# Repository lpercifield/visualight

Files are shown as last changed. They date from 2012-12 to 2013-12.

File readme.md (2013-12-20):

###**Visualight Hardware and Firmware**
Server code is available from this repo

####**Release Candidate GREEN**

Current Firmware Version: 1.1 (RC GREEN) library
More information: [Visualight.org][1]

* Arduino Library can be found in Firmware > Visualight
* Wiki can be found [here][2]

------
	
####Features:
* Show color (version) of firmware when you do a reset
* Ability to enable/disable WiFly LEDs from Arduino (top-level)
* Special character support in SSIDs (now supports &^%$#()!@ in network name)

####Fixes:
* Easier to reset WiFi with button (processButton() added to reconnect loops
* Debug toggling from Arduino?

[1]:http://visualight.org
[2]:https://github.com/lpercifield/visualight/wiki
[3]:https://github.com/lpercifield/Visualight_Server

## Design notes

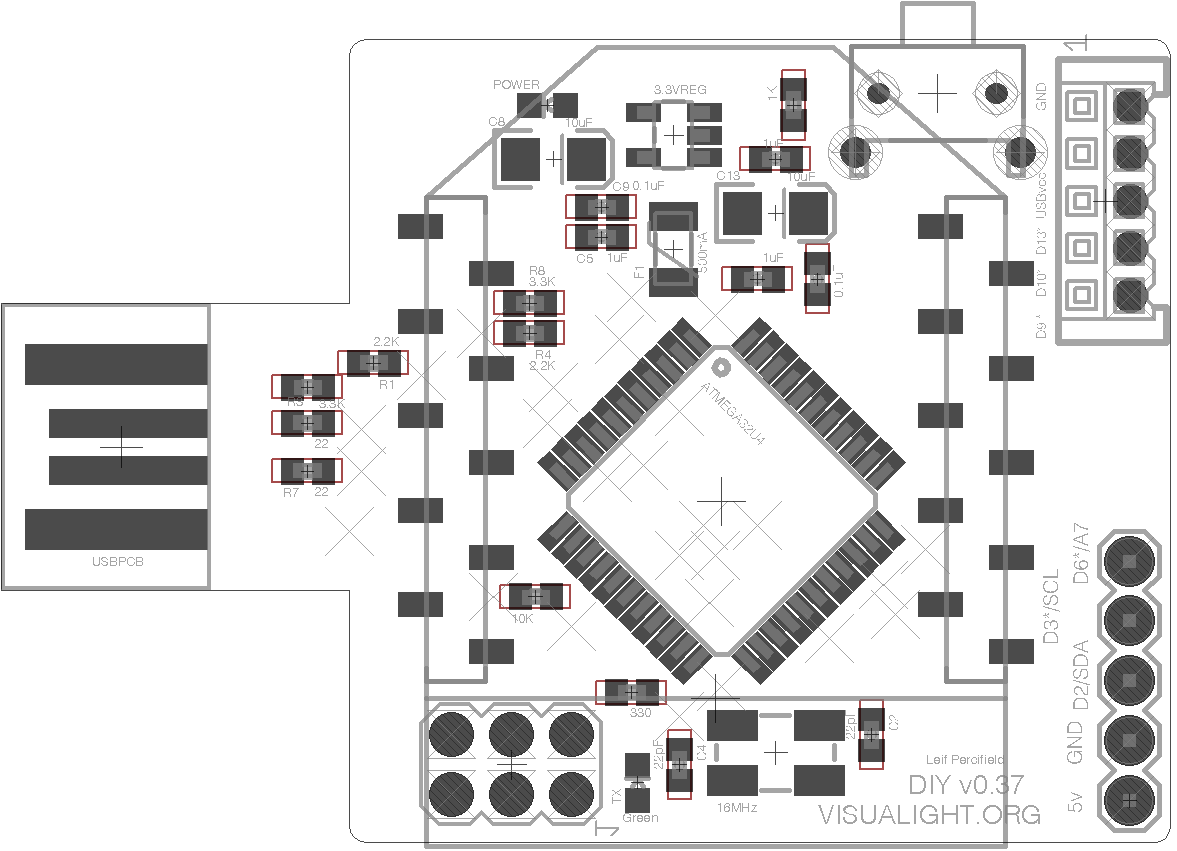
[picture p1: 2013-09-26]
Hardware/dev/DIY/DIY_037.png

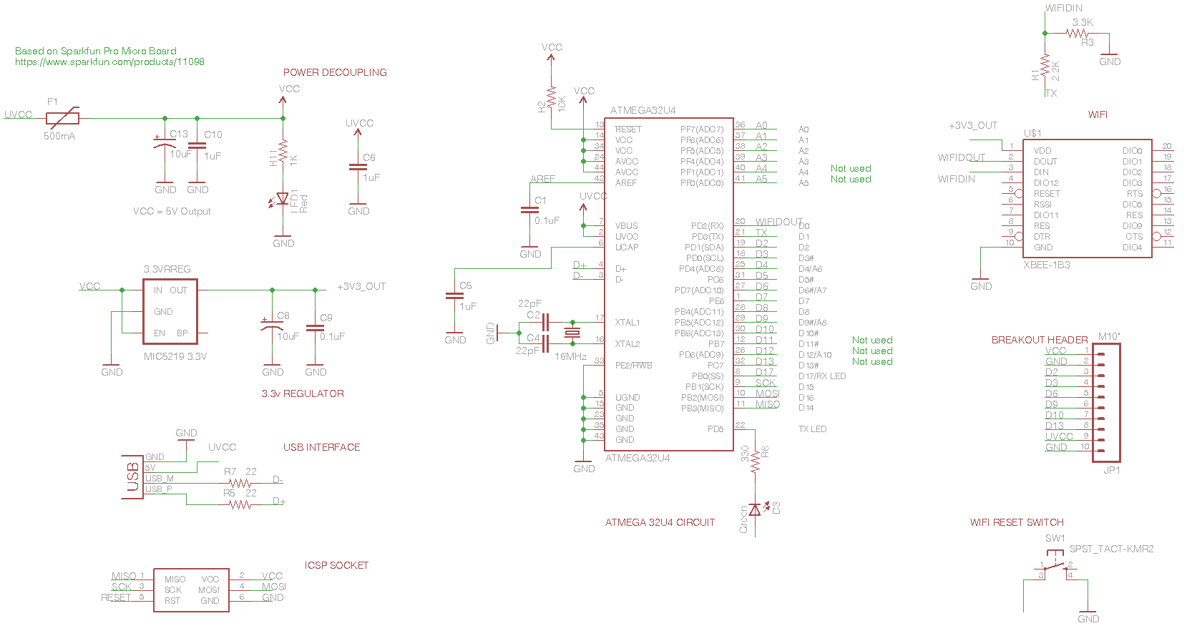
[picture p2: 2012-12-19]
Hardware/dev/DIY/DIY Schematic.png

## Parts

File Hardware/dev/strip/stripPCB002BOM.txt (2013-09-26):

Partlist exported from /Users/leifpercifield/Dropbox/visualightGithub/visualight/Hardware/strip/stripPCB002.sch at 8/27/13 11:21 AM

Qty Value                 Device                Package                   Parts       Description                                                                      MF MPN OC_FARNELL OC_NEWARK PROD_ID    VALUE       
1                         W237-4                W237-4                    X1          WAGO SCREW CLAMP                                                                        unknown    unknown                          
2   0.1uF                 CAP0402-CAP           0402-CAP                  C1, C9      Capacitor                                                                                                                           
1   10K                   RESISTOR0402-RES      0402-RES                  R2          Resistor                                                                                                                            
2   10uF                  CAP_POL1206           EIA3216                   C8, C13     Capacitor Polarized                                                                                                                 
1   16MHz                 CRYSTAL5X3            CRYSTAL-SMD-5X3           Y1          Crystals                                                                                                                            
1   1K                    RESISTOR0402-RES      0402-RES                  R11         Resistor                                                                                                                            
3   1uF                   CAP0402-CAP           0402-CAP                  C5, C6, C10 Capacitor                                                                                                                           
2   2.2K                  RESISTOR0402-RES      0402-RES                  R1, R4      Resistor                                                                                                                            
2   22                    RESISTOR0402-RES      0402-RES                  R5, R7      Resistor                                                                                                                            
2   22pF                  CAP0402-CAP           0402-CAP                  C2, C4      Capacitor                                                                                                                           
2   3.3K                  RESISTOR0402-RES      0402-RES                  R3, R8      Resistor                                                                                                                            
1   330                   RESISTOR0402-RES      0402-RES                  R6          Resistor                                                                                                                            
1   500mA                 PTCSMD                PTC-1206                  F1          Resettable Fuse PTC                                                                                                                 
1   ATMEGA32U4            ATMEGA32U4TQFP        SPARKFUN-DIGITALIC_TQFP44 ATMEGA32U4  Atmel 44-pin 8-bit Microcontroller with 32KBytes of ISP Flash and USB Controller                                                    
1   AVRISP-6              AVRISP-6              AVRISP                    ISP1        AVR ISP HEADER                                                                                                                      
1   Green                 LED0603               LED-0603                  TX          LEDs                                                                                                                                
1   MIC5219 3.3V          V_REG_MIC52193.3V     SOT23-5                   3.3VREG     V_REG MIC5219                                                                                                VREG-09872 MIC5219 3.3V
1   MIC5239               MIC5239               SOT223                    U$2                                                                                                                                             
3   N-HEXFET-2D_SOT232-   N-HEXFET-2D_SOT232-   SOT223                    Q1, Q2, Q3  HEXFET® Power MOSFET 2 Drain connects                                                                                               
1   POWER_JACKPTH         POWER_JACKPTH         POWER_JACK_PTH            J1          Power Jack                                                                                                                          
1   Red                   LED0603               LED-0603                  POWER       LEDs                                                                                                                                
1   SWITCH-MOMENTARY-2SMD SWITCH-MOMENTARY-2SMD TACTILE_SWITCH_SMD        S1          Various NO switches- pushbuttons, reed, etc                                                                                         
1   USB-MICROB            USB-MICROB            USB-MICROB                X2          USB Connectors                                                                                               CONN-09505             
1   XBEE-1B3              XBEE-1B3              XBEE-SMD                  U$1         Xbee module footprints                                                                                       CONN-09042

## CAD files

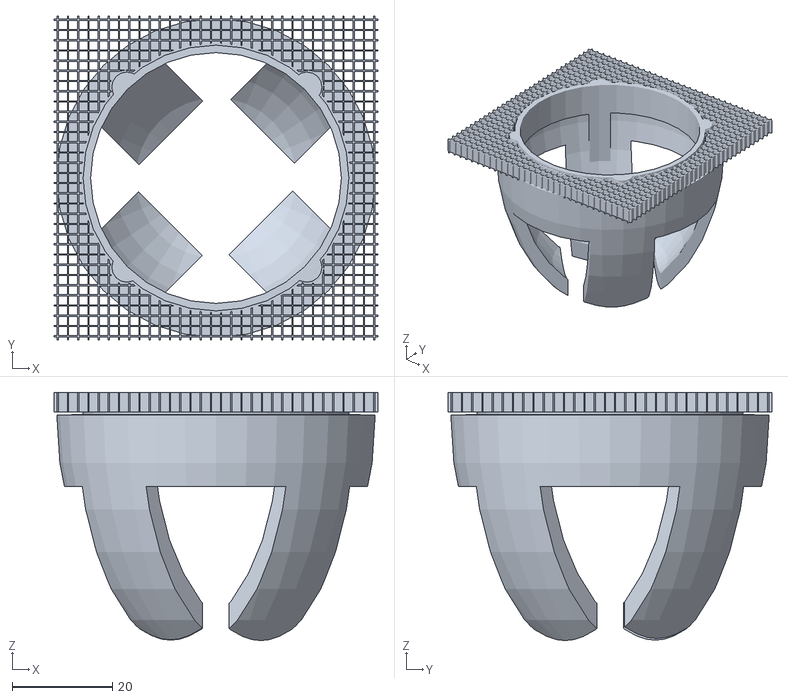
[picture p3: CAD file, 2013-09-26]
Hardware/dev/DIY_Visualight004/vis_04_BOT_XRAFT2.stl
64.6 x 64.6 x 49.5

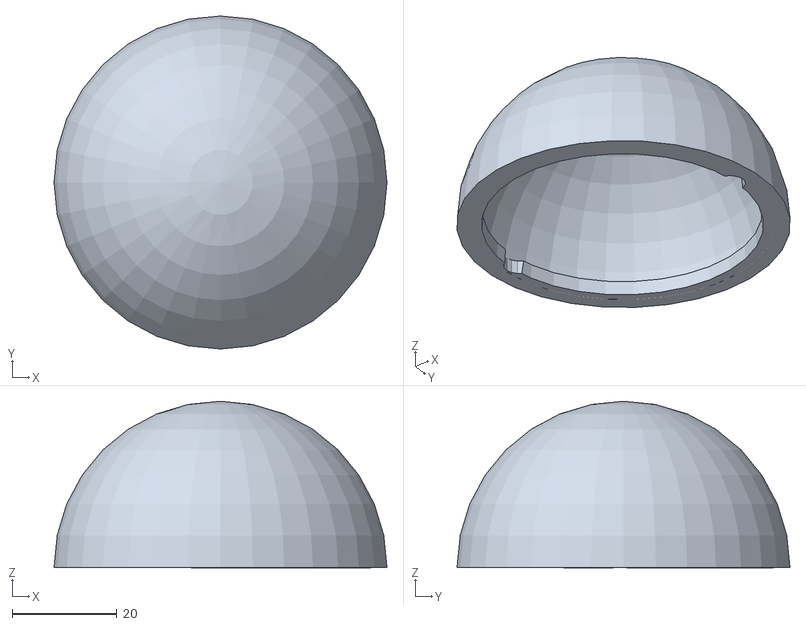
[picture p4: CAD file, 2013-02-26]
Hardware/dev/diy_visualight_top_smalllip.stl
63.5 x 63.5 x 31.8

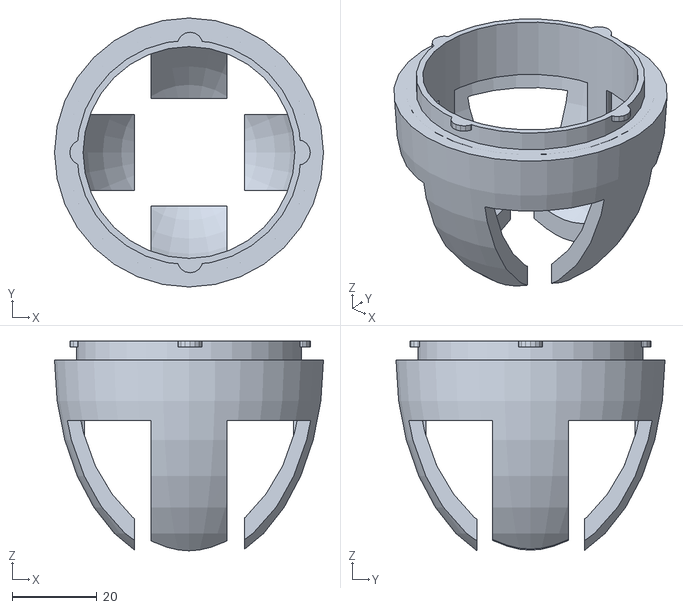
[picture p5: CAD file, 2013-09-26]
Hardware/dev/newtabs/visbot_tall_newlip.stl
63.5 x 63.5 x 49.5

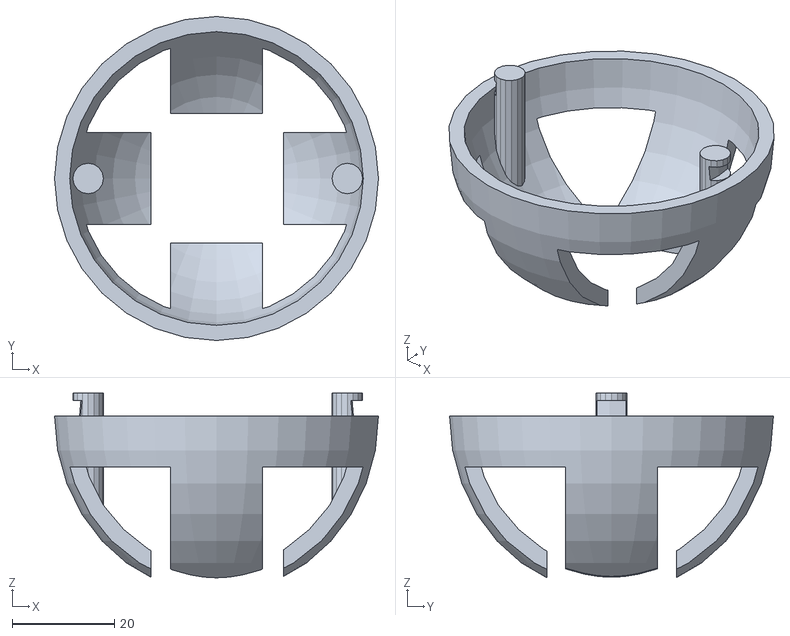
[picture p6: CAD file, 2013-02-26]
Hardware/dev/diy_visualight_bottom.stl
63.5 x 63.5 x 36.2

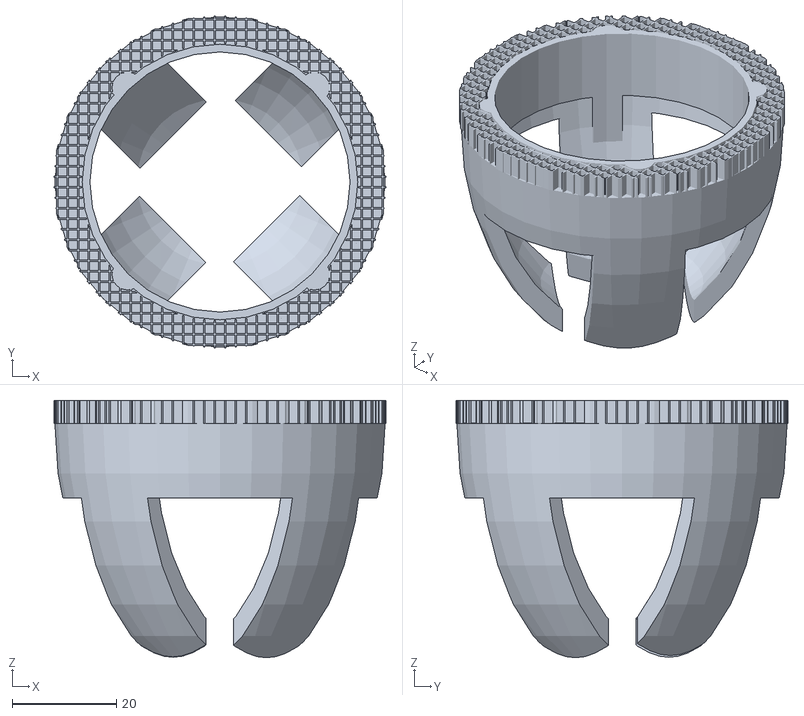
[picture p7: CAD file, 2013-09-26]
Hardware/dev/DIY_Visualight004/vis_04_BOT_XRAFT.stl
63.8 x 63.8 x 49.5

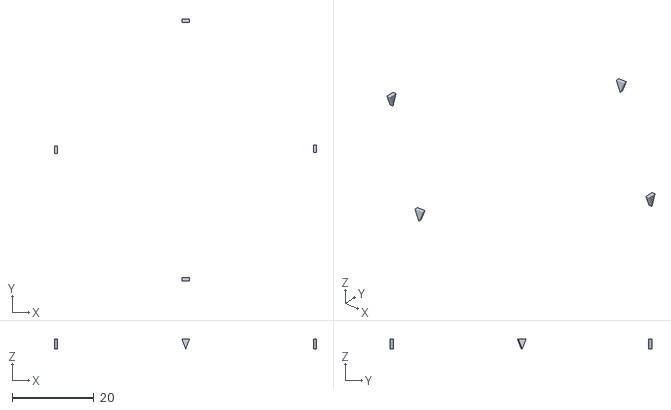
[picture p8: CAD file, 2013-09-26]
Hardware/dev/newtabs/vistop_markers.stl
64.3 x 64.2 x 2.39

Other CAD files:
Hardware/dev/newtabs_clearence/vis_top_newtab.stl
Hardware/dev/Visualight_Housing/diy_visualight_top.obj
Hardware/dev/DIY_Visualight004/vis_04_BOT.stl
Hardware/dev/newtabs/vistop_nomarkers.stl
Hardware/dev/newtabs_clearence/vis_bot_newtab.stl
Hardware/dev/Visualight_Housing/diy_visualight_bottom.obj
Hardware/dev/DIY_Visualight004/vis_04_TOP.stl
Hardware/dev/diy_visualight_top.stl
Hardware/dev/newtabs/vistop_withmarkers.stl
Hardware/dev/diy_visualight_bottom.obj
Hardware/dev/diy_visualight_top.obj

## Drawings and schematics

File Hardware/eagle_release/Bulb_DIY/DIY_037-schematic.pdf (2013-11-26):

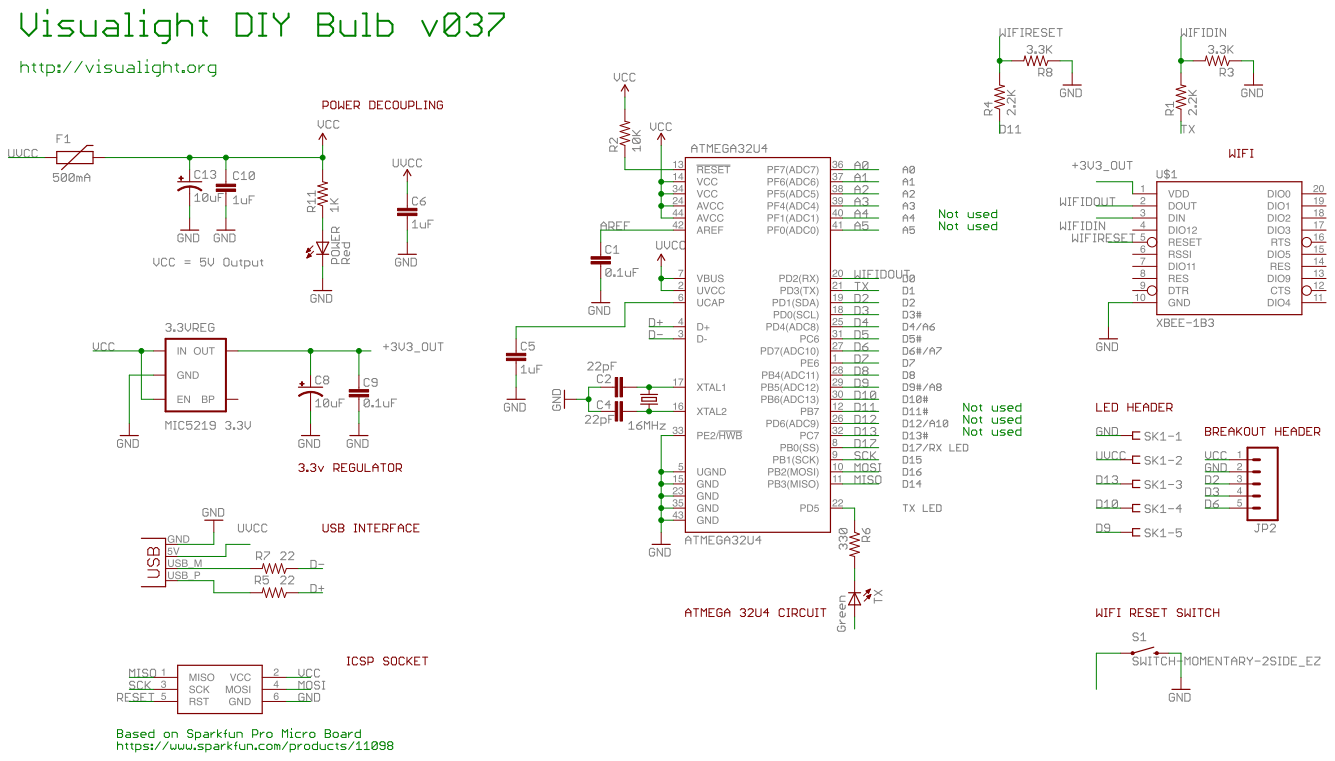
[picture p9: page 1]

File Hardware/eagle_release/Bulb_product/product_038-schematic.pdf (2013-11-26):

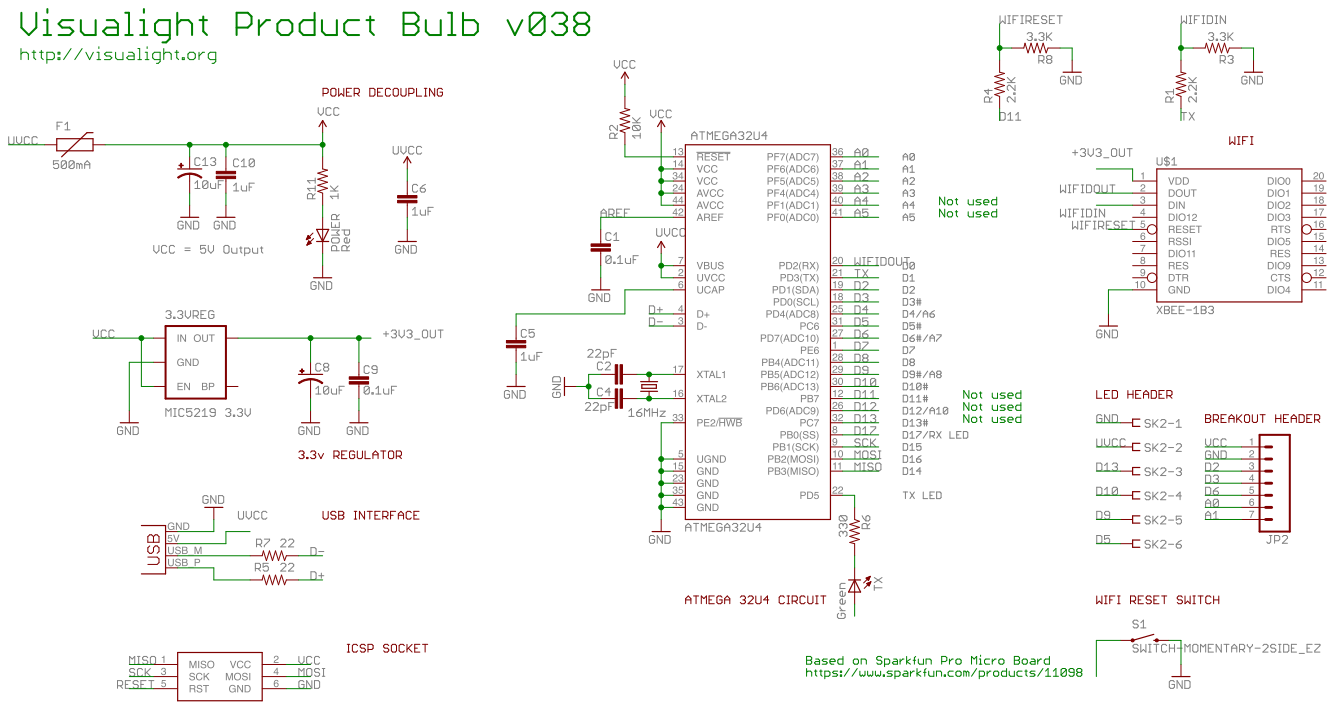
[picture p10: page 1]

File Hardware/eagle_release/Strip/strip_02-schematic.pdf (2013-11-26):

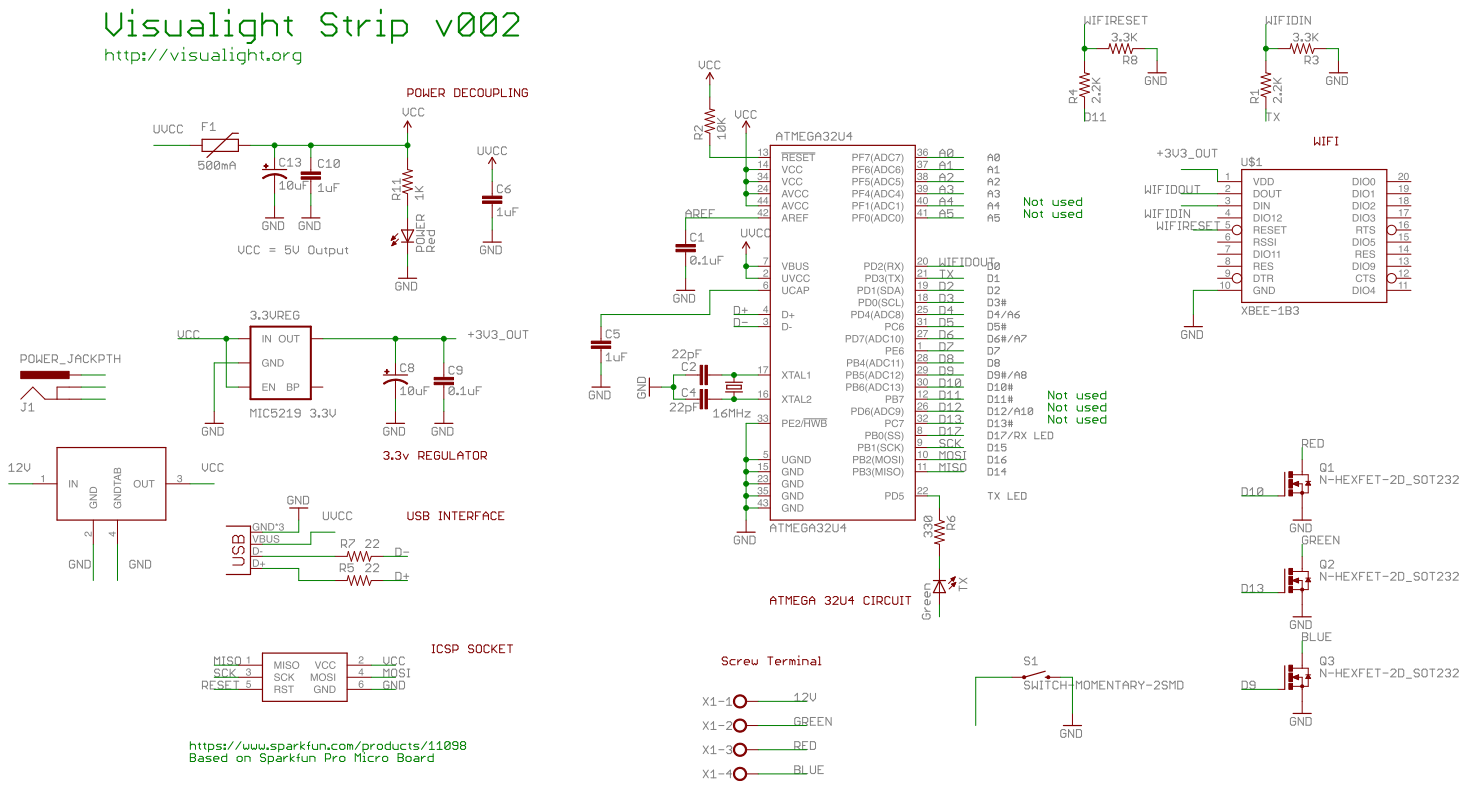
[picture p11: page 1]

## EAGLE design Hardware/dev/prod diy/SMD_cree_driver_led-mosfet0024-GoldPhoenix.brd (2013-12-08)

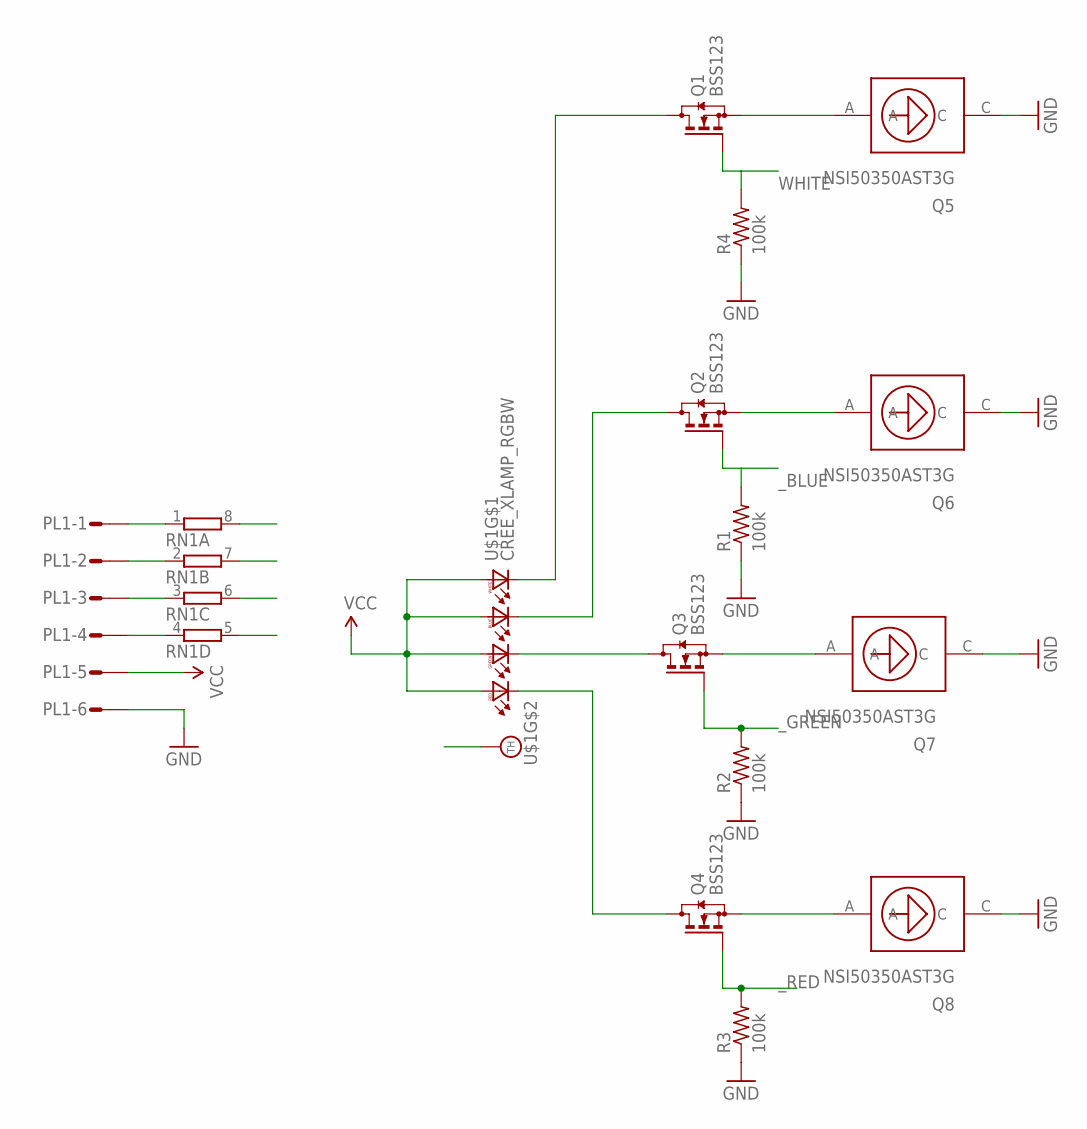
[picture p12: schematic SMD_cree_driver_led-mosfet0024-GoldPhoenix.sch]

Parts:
PL1: DF3-06R; DF3R-06
Q1, Q2, Q3, Q4: BSS123; SOT23
Q5, Q6, Q7, Q8: NSI50350AST3G; SMC-2
R1, R2, R3, R4: 100k; R0402
RN1: 4R-N0603-ARC; 0603-ARC
U$1: CREE_XLAMP_RGBW; CREE_XLAMP_XML

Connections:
BLUE_DRIVER: Q2.3 (D), U$1.6 (BC)
BLUE_PWM_IN: PL1.3, RN1.3 (1)
GND: PL1.6, Q5.C, Q6.C, Q7.C, Q8.C, R1.1, R2.1, R3.1, R4.1
GREEN_DRIVER: Q3.3 (D), U$1.7 (GC)
GREEN_PWM_IN: PL1.4, RN1.4 (1)
unnamed: Q2.2 (S), Q6.A
unnamed: Q4.2 (S), Q8.A
unnamed: Q3.2 (S), Q7.A
unnamed: Q1.2 (S), Q5.A
RED_DRIVER: Q4.3 (D), U$1.8 (RC)
RED_PWM_IN: PL1.2, RN1.2 (1)
THERM: U$1.P$1 (TH)
VCC: PL1.5, U$1.1 (RA), U$1.2 (GA), U$1.3 (BA), U$1.4 (WA)
WHITE: Q1.1 (G), R4.2, RN1.8 (2)
WHITE_DRIVER: Q1.3 (D), U$1.5 (WC)
WHITE_PWM_IN: PL1.1, RN1.1
_BLUE: Q2.1 (G), R1.2, RN1.6 (2)
_GREEN: Q3.1 (G), R2.2, RN1.5 (2)
_RED: Q4.1 (G), R3.2, RN1.7 (2)

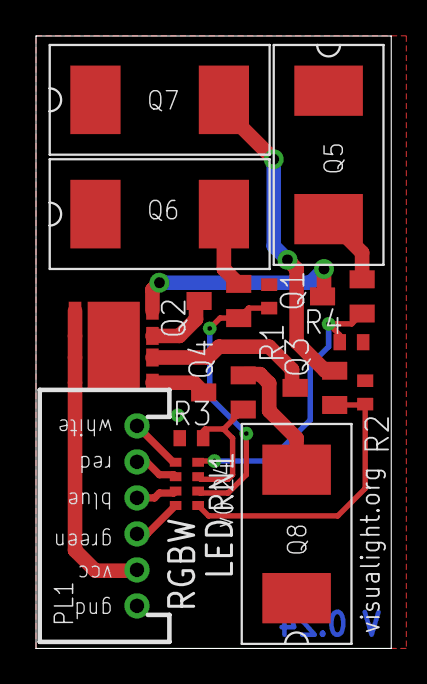
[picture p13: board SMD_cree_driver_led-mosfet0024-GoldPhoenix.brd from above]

Board: 2 copper layers, 19.7 x 34.0 mm, 15 parts (0 on the bottom side), 18 nets.

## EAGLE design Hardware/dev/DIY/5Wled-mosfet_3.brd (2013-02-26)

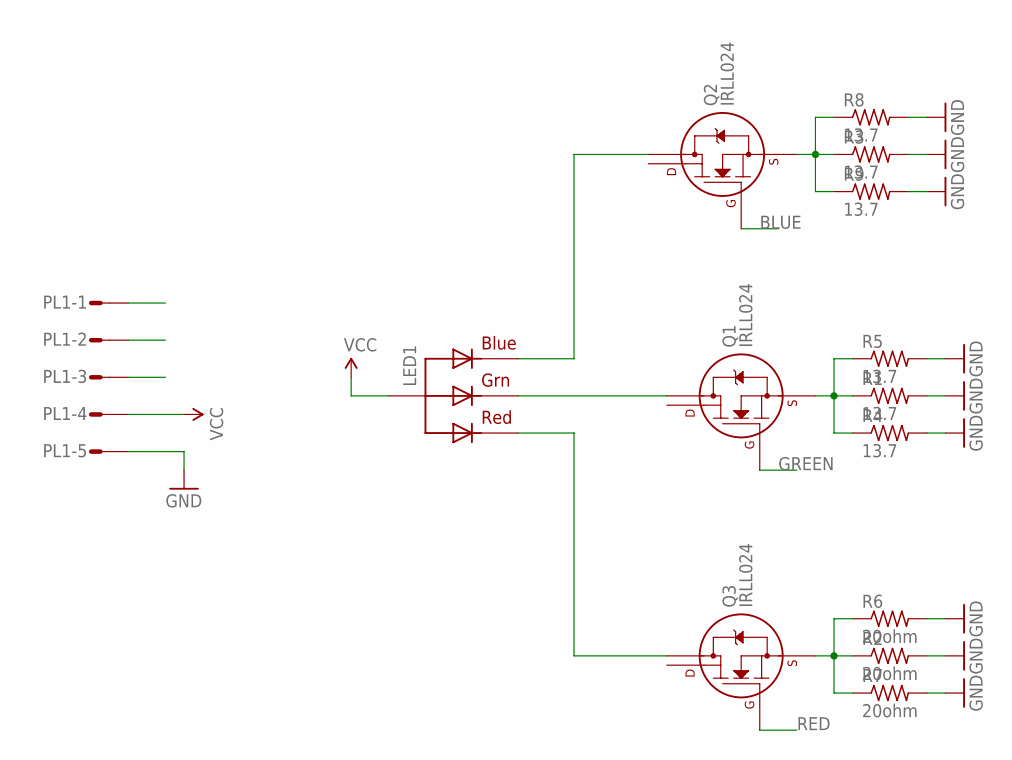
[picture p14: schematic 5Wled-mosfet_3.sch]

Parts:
LED1: RGBLED_CA4.5MM; 5WRGBLED
PL1: DF3-05R; DF3R-05
Q1, Q2, Q3: IRLL024; SOT-223
R1, R3, R4, R5, R8, R9: 13.7; R1210
R2, R6, R7: 20ohm; R1210

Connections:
BLUE: PL1.3, Q2.1 (G)
GND: PL1.5, R1.2, R2.2, R3.2, R4.2, R5.2, R6.2, R7.2, R8.2, R9.2
GREEN: PL1.1, Q1.1 (G)
unnamed: LED1.3 (GREEN), Q1.2 (D1)
unnamed: LED1.1 (BLUE), Q2.2 (D1)
unnamed: LED1.2 (RED), Q3.2 (D1)
unnamed: Q1.3 (S), R1.1, R4.1, R5.1
unnamed: Q3.3 (S), R2.1, R6.1, R7.1
unnamed: Q2.3 (S), R3.1, R8.1, R9.1
RED: PL1.2, Q3.1 (G)
VCC: LED1.4 (VCC), PL1.4

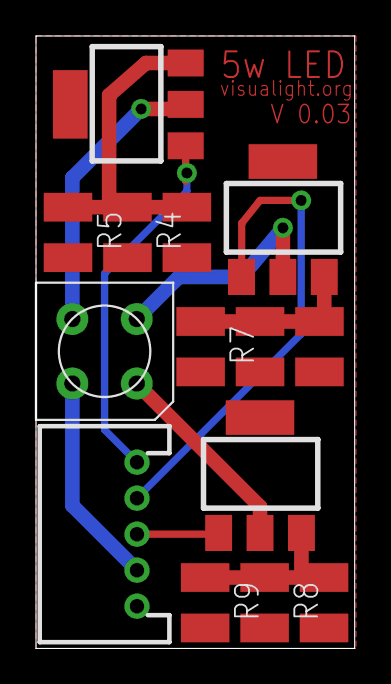
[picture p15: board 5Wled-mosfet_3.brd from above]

Board: 2 copper layers, 17.7 x 34.0 mm, 14 parts (0 on the bottom side), 11 nets.

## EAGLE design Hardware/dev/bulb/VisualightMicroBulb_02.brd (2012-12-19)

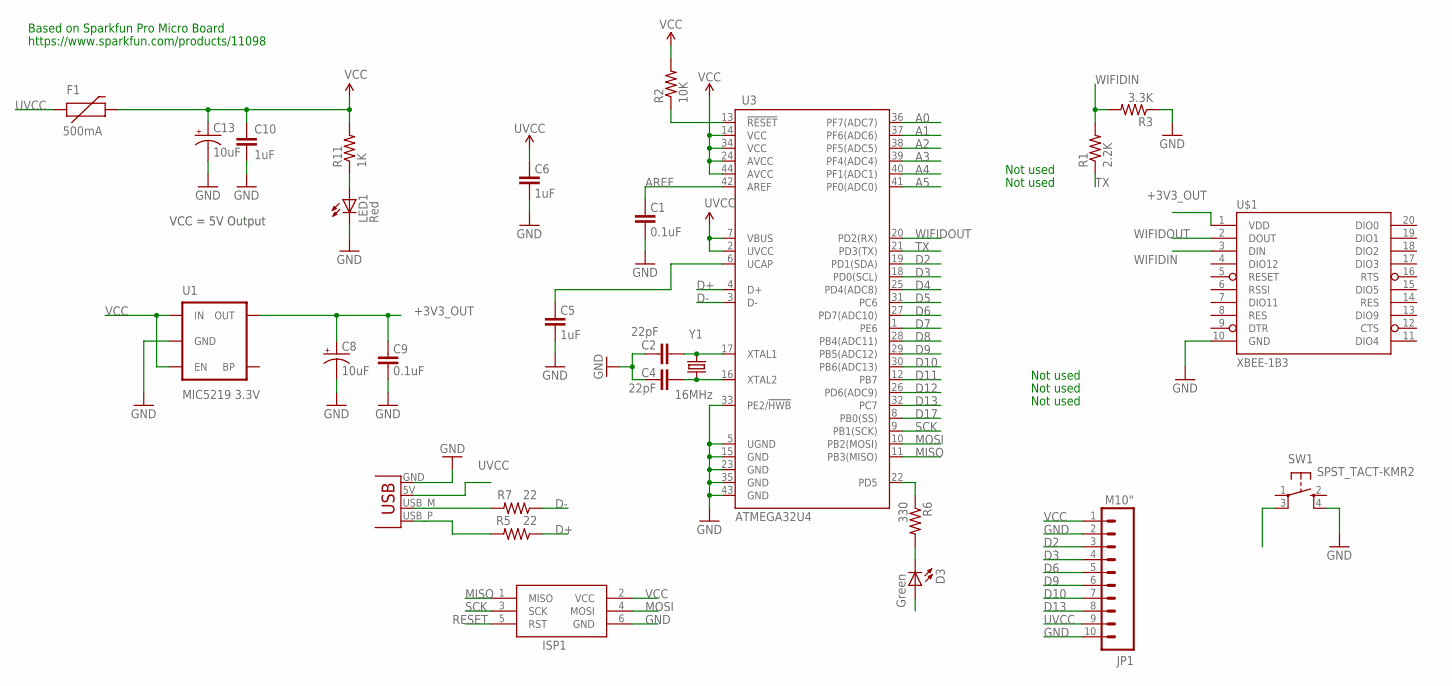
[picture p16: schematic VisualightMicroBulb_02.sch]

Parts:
C1, C9: 0.1uF; 0402-CAP
C2, C4: 22pF; 0402-CAP
C5, C6, C10: 1uF; 0402-CAP
C8, C13: 10uF; EIA3216
D3: Green; LED-0603
F1: 500mA; PTC-1206
ISP1: AVRISP-6; AVRISP
JP1: M10"; 1X10
LED1: Red; LED-0603
R1: 2.2K; 0402-RES
R2: 10K; 0402-RES
R3: 3.3K; 0402-RES
R5, R7: 22; 0402-RES
R6: 330; 0402-RES
R11: 1K; 0402-RES
SW1: SPST_TACT-KMR2; KMR2
U1: MIC5219 3.3V; SOT23-5
U3: ATMEGA32U4; SPARKFUN-DIGITALIC_TQFP44
U$1: XBEE-1B3; XBEE-SMD
X2: USBPCB; USB-A-PCB
Y1: 16MHz; CRYSTAL-SMD-5X3

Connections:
+3V3_OUT: C8.A (+), C9.2, U1.5 (OUT), U$1.1 (VDD)
A0: U3.36 (PF7(ADC7))
A1: U3.37 (PF6(ADC6))
A2: U3.38 (PF5(ADC5))
A3: U3.39 (PF4(ADC4))
A4: U3.40 (PF1(ADC1))
A5: U3.41 (PF0(ADC0))
AREF: C1.2, U3.42 (AREF)
D2: JP1.3, U3.19 (PD1(SDA))
D3: JP1.4, U3.18 (PD0(SCL))
D4: U3.25 (PD4(ADC8))
D5: U3.31 (PC6)
D6: JP1.5, U3.27 (PD7(ADC10))
D7: SW1.3 (P1), U3.1 (PE6)
D8: U3.28 (PB4(ADC11))
D9: JP1.6, U3.29 (PB5(ADC12))
D10: JP1.7, U3.30 (PB6(ADC13))
D11: U3.12 (PB7)
D12: U3.26 (PD6(ADC9))
D13: JP1.8, U3.32 (PC7)
D17: U3.8 (PB0(SS))
D+: R5.1, U3.4 (D+)
D-: R7.1, U3.3 (D-)
GND: C1.1, C2.2, C4.2, C5.1, C6.1, C8.C (-), C9.1, C10.2, C13.C (-), ISP1.6 (GND), JP1.2, JP1.10, LED1.C, R3.1, SW1.4 (S1), U1.2 (GND), U3.5 (UGND), U3.15 (GND), U3.23 (GND), U3.33 (PE2/!HWB), U3.35 (GND), U3.43 (GND), U$1.10 (GND), X2.GND
MISO: ISP1.1 (MISO), U3.11 (PB3(MISO))
MOSI: ISP1.4 (MOSI), U3.10 (PB2(MOSI))
unnamed: C4.1, U3.16 (XTAL2), Y1.1
unnamed: C2.1, U3.17 (XTAL1), Y1.3 (2)
unnamed: C5.2, U3.6 (UCAP)
unnamed: R7.2, X2.USB_M (D-)
unnamed: D3.C, R6.2
unnamed: R5.2, X2.USB_P (D+)
unnamed: LED1.A, R11.1
RESET: ISP1.5 (RST), R2.1, U3.13 (!RESET)
SCK: ISP1.3 (SCK), U3.9 (PB1(SCK))
TX: R1.1, U3.21 (PD3(TX))
TXLED: R6.1, U3.22 (PD5)
UVCC: C6.2, F1.1, JP1.9, U3.2 (UVCC), U3.7 (VBUS), X2.5V (VBUS)
VCC: C10.1, C13.A (+), D3.A, F1.2, ISP1.2 (VCC), JP1.1, R2.2, R11.2, U1.1 (IN), U1.3 (EN), U3.14 (VCC), U3.24 (AVCC), U3.34 (VCC), U3.44 (AVCC)
WIFIDIN: R1.2, R3.2, U$1.3 (DIN)
WIFIDOUT: U3.20 (PD2(RX)), U$1.2 (DOUT)

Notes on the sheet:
VCC = 5V Output
Not used
Based on Sparkfun Pro Micro Board
https://www.sparkfun.com/products/11098

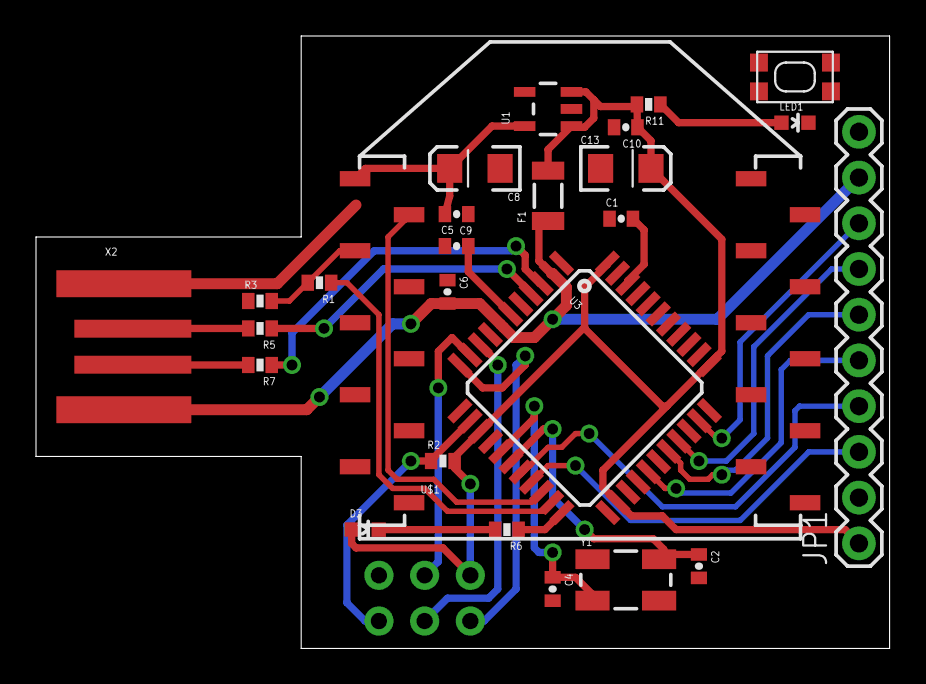
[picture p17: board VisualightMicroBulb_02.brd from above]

Board: 2 copper layers, 47.4 x 34.0 mm, 27 parts (1 on the bottom side), 29 nets.

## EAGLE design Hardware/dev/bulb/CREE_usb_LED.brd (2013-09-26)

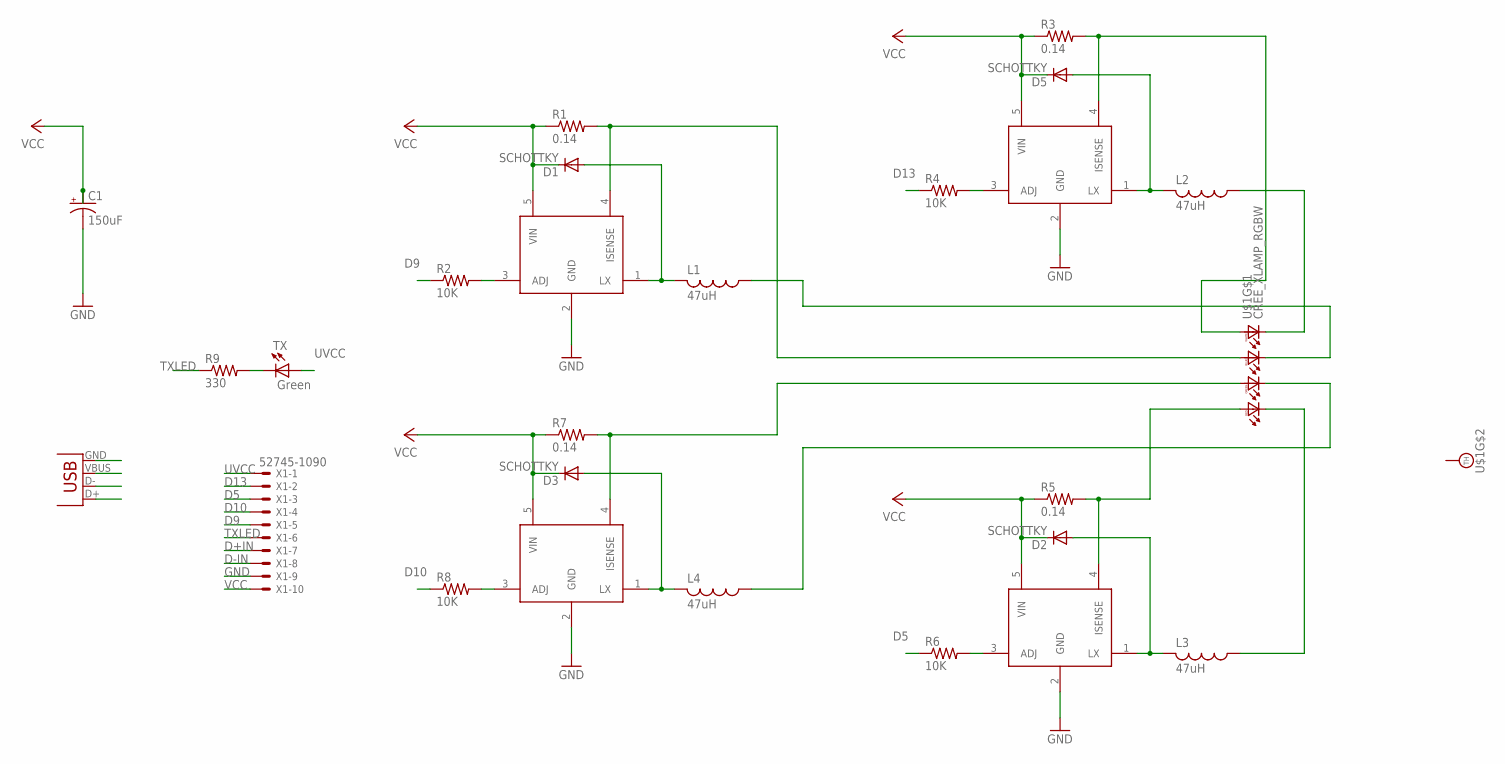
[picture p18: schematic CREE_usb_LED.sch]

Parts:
C1: 150uF; 175TMP-0810
D1, D2, D3, D5: SCHOTTKY; DO214AC
L1, L2, L3, L4: 47uH; TDK6045
R1, R3, R5, R7: 0.14; R0805
R2, R4, R6, R8: 10K; R0603
R9: 330; 0402-RES
TX: Green; LED-0603
U$1: CREE_XLAMP_RGBW; CREE_XLAMP_XML
U$2, U$3, U$4, U$6: ZLED7000-LEDDRIVER; SOT89-5
X1: 52745-1090
X2: USB-MICROB

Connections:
D5: R6.1, X1.3
D9: R2.1, X1.5
D10: R8.1, X1.4
D13: R4.1, X1.2
D+IN: X1.7, X2.D+
D-IN: X1.8, X2.D-
GND: C1.-, U$2.2 (GND), U$3.2 (GND), U$4.2 (GND), U$6.2 (GND), X1.9, X2.GND
unnamed: R2.2, U$2.3 (ADJ)
unnamed: R9.2, TX.C
unnamed: R1.2, U$1.3 (BA), U$2.4 (ISENSE)
unnamed: L2.1, U$1.5 (WC)
unnamed: D1.A, L1.2, U$2.1 (LX)
unnamed: R3.2, U$1.4 (WA), U$6.4 (ISENSE)
unnamed: D5.A, L2.2, U$6.1 (LX)
unnamed: R4.2, U$6.3 (ADJ)
unnamed: L1.1, U$1.6 (BC)
unnamed: R5.2, U$1.1 (RA), U$3.4 (ISENSE)
unnamed: D2.A, L3.2, U$3.1 (LX)
unnamed: R6.2, U$3.3 (ADJ)
unnamed: L4.1, U$1.7 (GC)
unnamed: R7.2, U$1.2 (GA), U$4.4 (ISENSE)
unnamed: D3.A, L4.2, U$4.1 (LX)
unnamed: R8.2, U$4.3 (ADJ)
unnamed: L3.1, U$1.8 (RC)
TXLED: R9.1, X1.6
UVCC: TX.A, X1.1, X2.VBUS
VCC: C1.+, D1.C, D2.C, D3.C, D5.C, R1.1, R3.1, R5.1, R7.1, U$2.5 (VIN), U$3.5 (VIN), U$4.5 (VIN), U$6.5 (VIN), X1.10

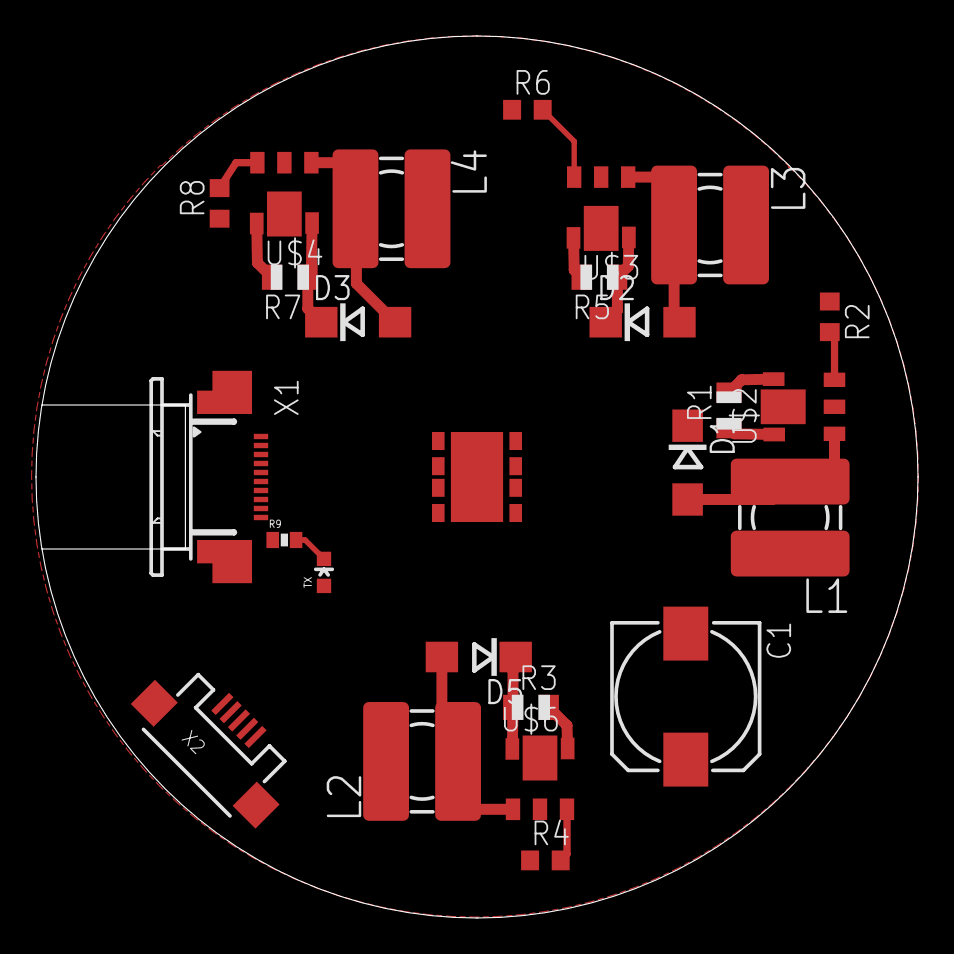
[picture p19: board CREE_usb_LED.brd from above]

Board: 2 copper layers, 49.0 x 49.0 mm, 26 parts (0 on the bottom side), 27 nets.

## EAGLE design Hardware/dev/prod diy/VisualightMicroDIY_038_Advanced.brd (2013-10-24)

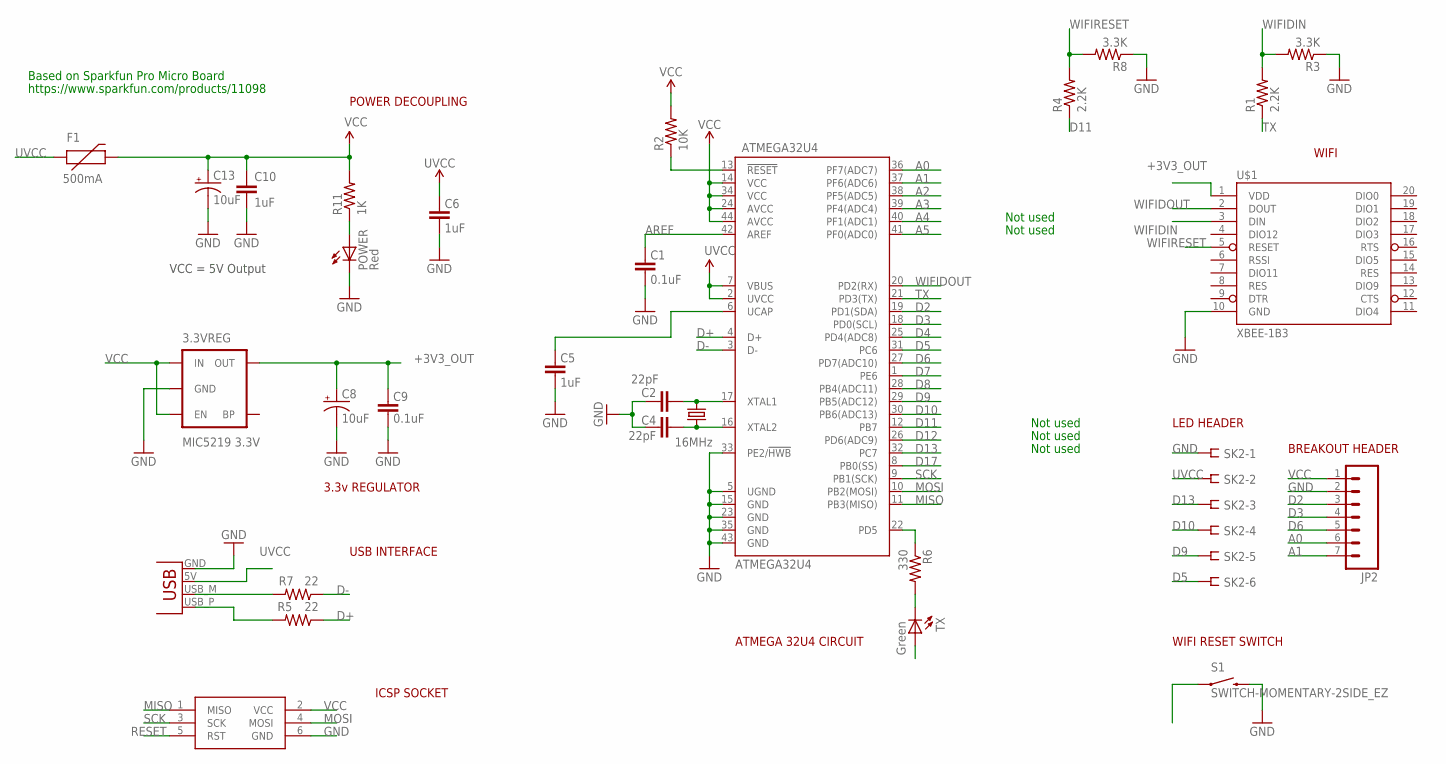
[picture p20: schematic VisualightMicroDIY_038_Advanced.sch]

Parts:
3.3VREG: MIC5219 3.3V; SOT23-5
ATMEGA32U4: ATMEGA32U4; SPARKFUN-DIGITALIC_TQFP44
C1, C9: 0.1uF; 0402-CAP
C2, C4: 22pF; 0402-CAP
C5, C6, C10: 1uF; 0402-CAP
C8, C13: 10uF; EIA3216
F1: 500mA; PTC-1206
ISP1: AVRISP-6; AVRISP
JP2: M07; 1X07
POWER: Red; LED-0603
R1, R4: 2.2K; 0402-RES
R2: 10K; 0402-RES
R3, R8: 3.3K; 0402-RES
R5, R7: 22; 0402-RES
R6: 330; 0402-RES
R11: 1K; 0402-RES
S1: SWITCH-MOMENTARY-2SIDE_EZ; TACTILE-PTH-SIDEEZ
SK2: DF3-06S; DF3S-06
TX: Green; LED-0603
U$1: XBEE-1B3; XBEE-SMD
X2: USBPCB; USB-A-PCB
Y1: 16MHz; CRYSTAL-SMD-5X3

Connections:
+3V3_OUT: 3.3VREG.5 (OUT), C8.A (+), C9.2, U$1.1 (VDD)
A0: ATMEGA32U4.36 (PF7(ADC7)), JP2.6
A1: ATMEGA32U4.37 (PF6(ADC6)), JP2.7
A2: ATMEGA32U4.38 (PF5(ADC5))
A3: ATMEGA32U4.39 (PF4(ADC4))
A4: ATMEGA32U4.40 (PF1(ADC1))
A5: ATMEGA32U4.41 (PF0(ADC0))
AREF: ATMEGA32U4.42 (AREF), C1.2
D2: ATMEGA32U4.19 (PD1(SDA)), JP2.3
D3: ATMEGA32U4.18 (PD0(SCL)), JP2.4
D4: ATMEGA32U4.25 (PD4(ADC8))
D5: ATMEGA32U4.31 (PC6), SK2.6
D6: ATMEGA32U4.27 (PD7(ADC10)), JP2.5
D7: ATMEGA32U4.1 (PE6), S1.1
D8: ATMEGA32U4.28 (PB4(ADC11))
D9: ATMEGA32U4.29 (PB5(ADC12)), SK2.5
D10: ATMEGA32U4.30 (PB6(ADC13)), SK2.4
D11: ATMEGA32U4.12 (PB7), R4.1
D12: ATMEGA32U4.26 (PD6(ADC9))
D13: ATMEGA32U4.32 (PC7), SK2.3
D17: ATMEGA32U4.8 (PB0(SS))
D+: ATMEGA32U4.4 (D+), R5.1
D-: ATMEGA32U4.3 (D-), R7.1
GND: 3.3VREG.2 (GND), ATMEGA32U4.5 (UGND), ATMEGA32U4.15 (GND), ATMEGA32U4.23 (GND), ATMEGA32U4.33 (PE2/!HWB), ATMEGA32U4.35 (GND), ATMEGA32U4.43 (GND), C1.1, C2.2, C4.2, C5.1, C6.1, C8.C (-), C9.1, C10.2, C13.C (-), ISP1.6 (GND), JP2.2, POWER.C, R3.1, R8.1, S1.2, SK2.1, U$1.10 (GND), X2.GND
MISO: ATMEGA32U4.11 (PB3(MISO)), ISP1.1 (MISO)
MOSI: ATMEGA32U4.10 (PB2(MOSI)), ISP1.4 (MOSI)
unnamed: ATMEGA32U4.16 (XTAL2), C4.1, Y1.1
unnamed: ATMEGA32U4.17 (XTAL1), C2.1, Y1.3 (2)
unnamed: ATMEGA32U4.6 (UCAP), C5.2
unnamed: R7.2, X2.USB_M (D-)
unnamed: R6.2, TX.C
unnamed: R5.2, X2.USB_P (D+)
unnamed: POWER.A, R11.1
RESET: ATMEGA32U4.13 (!RESET), ISP1.5 (RST), R2.1
SCK: ATMEGA32U4.9 (PB1(SCK)), ISP1.3 (SCK)
TX: ATMEGA32U4.21 (PD3(TX)), R1.1
TXLED: ATMEGA32U4.22 (PD5), R6.1
UVCC: ATMEGA32U4.2 (UVCC), ATMEGA32U4.7 (VBUS), C6.2, F1.1, SK2.2, X2.5V (VBUS)
VCC: 3.3VREG.1 (IN), 3.3VREG.3 (EN), ATMEGA32U4.14 (VCC), ATMEGA32U4.24 (AVCC), ATMEGA32U4.34 (VCC), ATMEGA32U4.44 (AVCC), C10.1, C13.A (+), F1.2, ISP1.2 (VCC), JP2.1, R2.2, R11.2, TX.A
WIFIDIN: R1.2, R3.2, U$1.3 (DIN)
WIFIDOUT: ATMEGA32U4.20 (PD2(RX)), U$1.2 (DOUT)
WIFIRESET: R4.2, R8.2, U$1.5 (RESET)

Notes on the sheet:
VCC = 5V Output
Not used
Based on Sparkfun Pro Micro Board
https://www.sparkfun.com/products/11098
USB INTERFACE
ICSP SOCKET
3.3v REGULATOR
POWER DECOUPLING
ATMEGA 32U4 CIRCUIT
WIFI RESET SWITCH
BREAKOUT HEADER
WIFI
LED HEADER

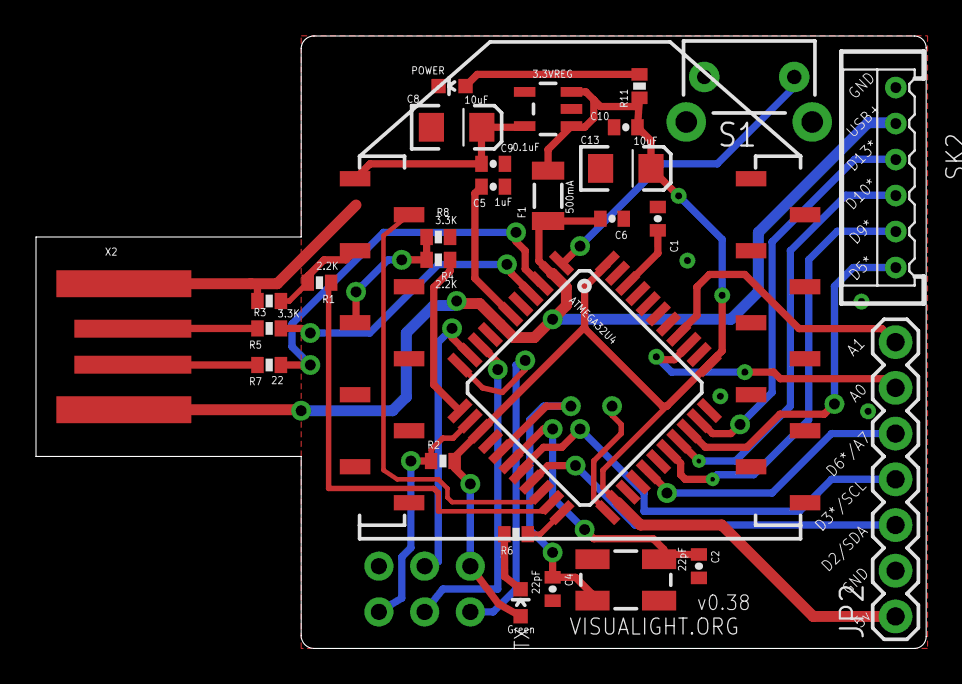
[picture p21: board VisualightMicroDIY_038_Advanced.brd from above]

Board: 2 copper layers, 49.5 x 34.0 mm, 30 parts (1 on the bottom side), 34 nets.

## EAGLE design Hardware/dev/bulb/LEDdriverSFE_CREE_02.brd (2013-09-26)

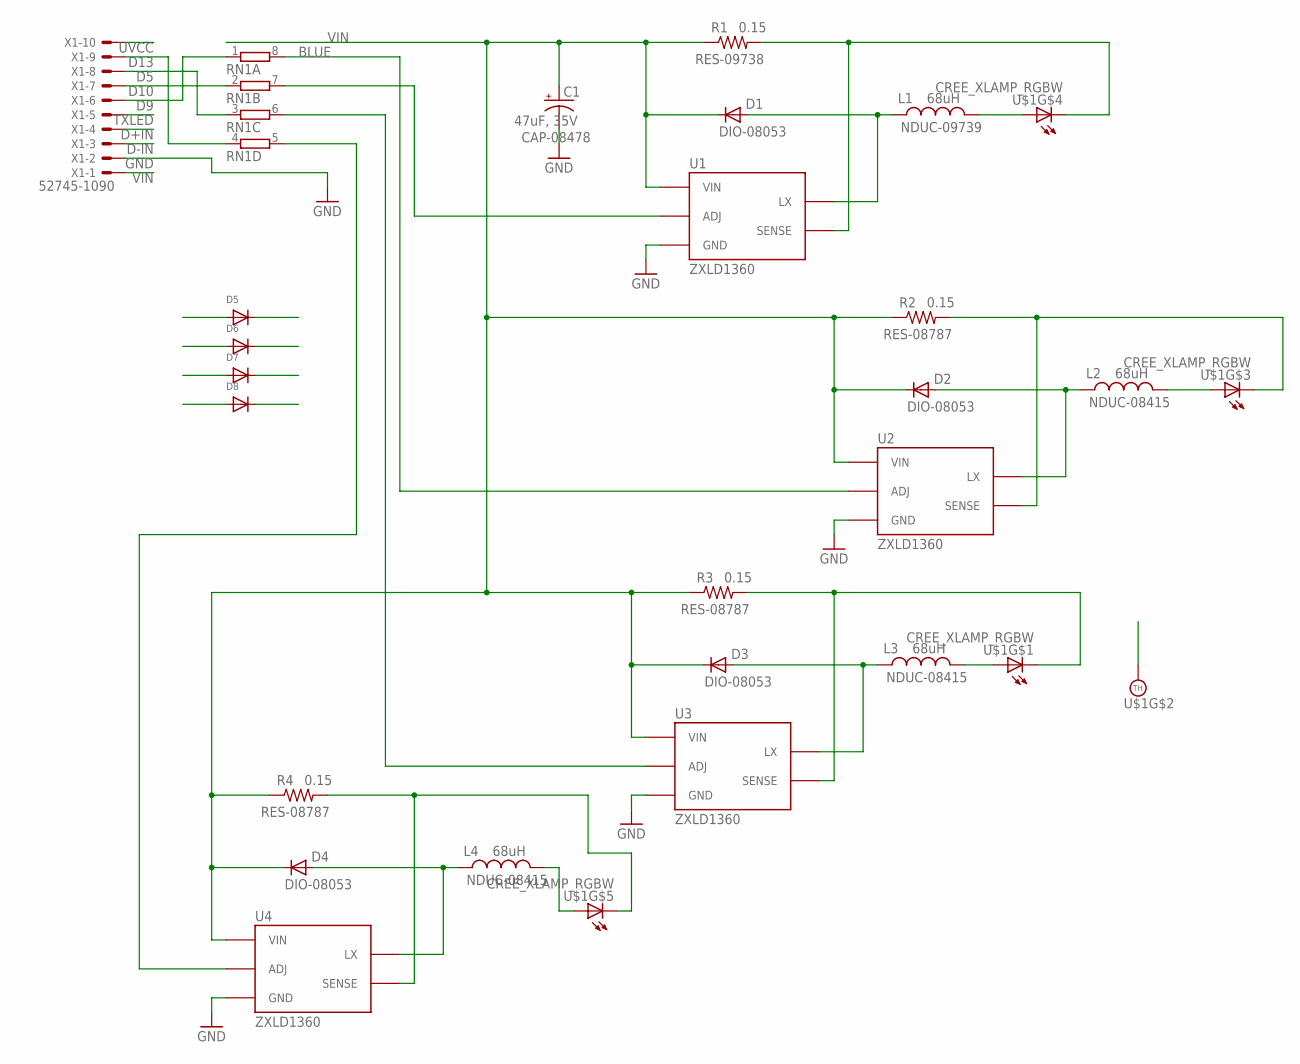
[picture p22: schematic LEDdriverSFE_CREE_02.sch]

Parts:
C1: 47uF, 35V; PANASONIC_D
D1, D2, D3, D4: MBRA140; SMA-DIODE
D5, D6, D7, D8: DIODESOD-323F; SOD-323F
L1, L2, L3, L4: 68uH; TDK6045
R1, R2, R3, R4: 0.15; 0603-RES
RN1: 4R-NEXBV8V; EXBV8V
U1, U2, U3, U4: ZXLD1360; SOT23-5
U$1: CREE_XLAMP_RGBW; CREE_XLAMP_XML
X1: 52745-1090

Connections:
BLUE: RN1.8 (2), U2.3 (ADJ)
D5: D8.C, RN1.3 (1), X1.8
D9: D5.C, RN1.1, X1.6
D10: D6.C, RN1.2 (1), X1.7
D13: D7.C, RN1.4 (1), X1.9
D+IN: X1.4
D-IN: X1.3
GND: C1.-, D5.A, D6.A, D7.A, D8.A, U1.2 (GND), U2.2 (GND), U3.2 (GND), U4.2 (GND), X1.2
GREEN: RN1.7 (2), U1.3 (ADJ)
unnamed: L1.2, U$1.3 (A)
unnamed: D2.A, L2.1, U2.1 (LX)
unnamed: R2.2, U2.4 (SENSE), U$1.7 (C)
unnamed: D1.A, L1.1, U1.1 (LX)
unnamed: R1.2, U1.4 (SENSE), U$1.6 (C)
unnamed: L2.2, U$1.2 (A)
unnamed: D3.A, L3.1, U3.1 (LX)
unnamed: R3.2, U3.4 (SENSE), U$1.8 (C)
unnamed: L3.2, U$1.1 (A)
unnamed: D4.A, L4.1, U4.1 (LX)
unnamed: R4.2, U4.4 (SENSE), U$1.5 (C)
unnamed: L4.2, U$1.4 (A)
RED: RN1.5 (2), U4.3 (ADJ)
THERM: U$1.P$1 (TH)
TXLED: X1.5
UVCC: X1.10
VIN: C1.+, D1.C, D2.C, D3.C, D4.C, R1.1, R2.1, R3.1, R4.1, U1.5 (VIN), U2.5 (VIN), U3.5 (VIN), U4.5 (VIN), X1.1
WHITE: RN1.6 (2), U3.3 (ADJ)

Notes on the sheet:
NDUC-09739
RES-09738
CAP-08478
DIO-08053
NDUC-08415
RES-08787

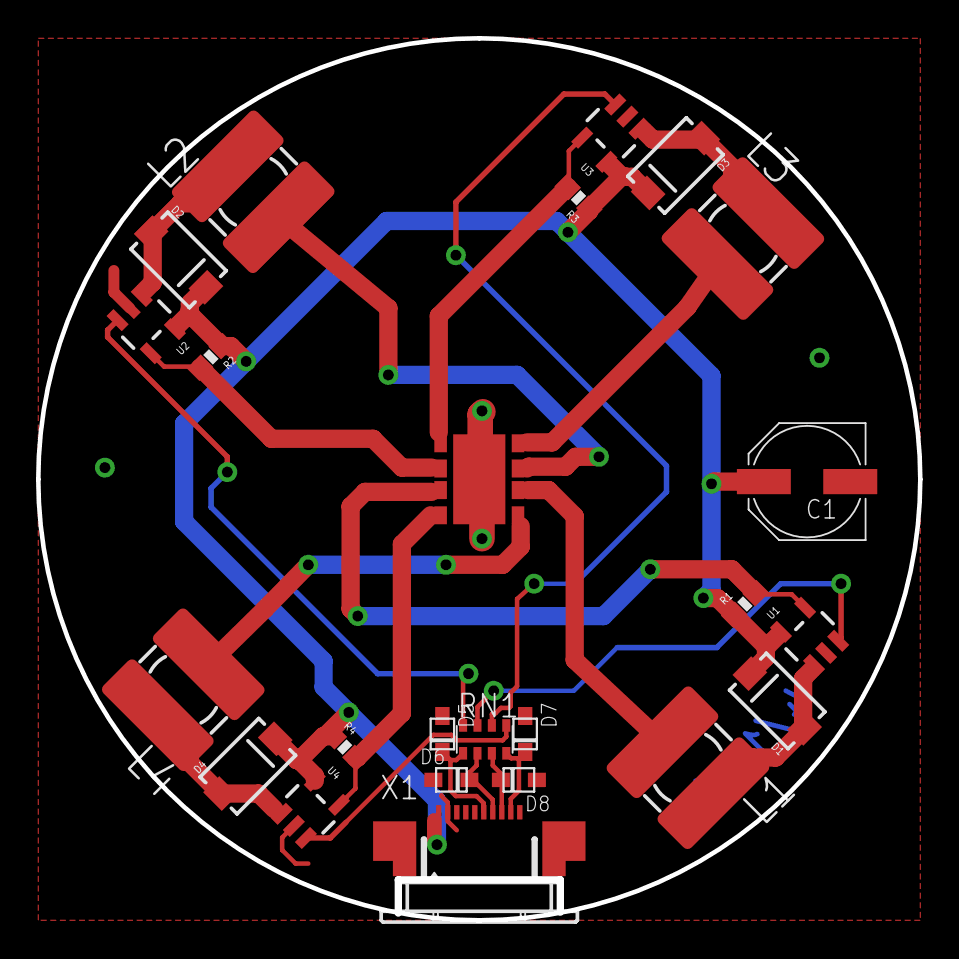
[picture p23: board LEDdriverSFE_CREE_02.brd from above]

Board: 2 copper layers, 49.0 x 49.0 mm, 24 parts (0 on the bottom side), 22 nets.

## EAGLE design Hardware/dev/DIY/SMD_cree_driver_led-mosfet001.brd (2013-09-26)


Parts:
PL1: DF3-05R; DF3R-05
Q4, Q5, Q6: BSS123; SOT23
R1, R2, R3: 100k; R0402
RN1: 2.2k; 0603-ARC
U$1: CREE_XLAMP_RGBW; CREE_XLAMP_XML
U$2, U$3, U$4: NSI50350AST3G; SMC-2

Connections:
BLUE: Q4.1 (G), R3.2, RN1.5 (2)
BLUE_OUT: PL1.3, RN1.4 (1)
GND: PL1.5, R1.1, R2.1, R3.1, U$2.C, U$3.C, U$4.C
GREEN: Q6.1 (G), R1.2, RN1.8 (2)
GREEN_OUT: PL1.1, RN1.1
unnamed: Q6.3 (D), U$1.6 (BC)
unnamed: Q5.3 (D), U$1.7 (GC)
unnamed: Q4.3 (D), U$1.8 (RC)
unnamed: Q6.2 (S), U$2.A
unnamed: Q4.2 (S), U$4.A
unnamed: Q5.2 (S), U$3.A
RED: Q5.1 (G), R2.2, RN1.6 (2)
RED_OUT: PL1.2, RN1.3 (1)
THERM: U$1.P$1 (TH)
VCC: PL1.4, U$1.1 (RA), U$1.2 (GA), U$1.3 (BA)


Board: 2 copper layers, 16.9 x 34.0 mm, 12 parts (0 on the bottom side), 14 nets.

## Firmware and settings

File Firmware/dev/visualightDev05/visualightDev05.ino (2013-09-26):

/*
 * WiFlyHQ Example httpserver.ino
 *
 * This sketch implements a simple Web server that waits for requests
 * and serves up a small form asking for a username, then when the
 * client posts that form the server sends a greeting page with the
 * user's name and an analog reading.
 *
 * This sketch is released to the public domain.
 *
 */

/* Notes:
 * Uses chunked message bodies to work around a problem where
 * the WiFly will not handle the close() of a client initiated
 * TCP connection. It fails to send the FIN to the client.
 * (WiFly RN-XV Firmware version 2.32).
 */

/* Work around a bug with PROGMEM and PSTR where the compiler always
 * generates warnings.
 */
#undef PROGMEM 
#define PROGMEM __attribute__(( section(".progmem.data") )) 
#undef PSTR 
#define PSTR(s) (__extension__({static prog_char __c[] PROGMEM = (s); &__c[0];})) 

#include <WiFlyHQ.h>
#include <EEPROM.h>
#include <Button.h>

//#include <SoftwareSerial.h>
//SoftwareSerial wifiSerial(8,9);

//#include <AltSoftSerial.h>
//AltSoftSerial wifiSerial(8,9);

WiFly wifly;

/* Change these to match your WiFi network */
//const char mySSID[] = "myssid";
//const char myPassword[] = "my-wpa-password";

void sendIndex();
void sendGreeting(char *name);
void send404();
void joinWifi();
void processServer();
void processClient();
void connectToSever();

char buf[80];
//char scanList[350];
char network[25];
char password[25];
boolean isServer = true;
char MAC[18];

int _red = 255;
int _green = 255;
int _blue = 255;
int _blinkMe = 0;
//without transistors
//const int redLED = 11;
//const int greenLED = 10;
//const int blueLED = 9;
//with transistors
const int redLED = 10;
const int greenLED = 9;
const int blueLED = 13;

boolean sink = false;

//Button button = Button(8, BUTTON_PULLUP_INTERNAL, true, 50);
const int resetButton = 7;

void setup()
{
  //colorLED(255,255,255);
  fadeOn();
  pinMode(resetButton, INPUT);
  digitalWrite(resetButton, HIGH);
  Serial.begin(115200);
  while(!Serial){
    ;
  }
  Serial.println(F("Starting"));
  Serial.print(F("Free memory: "));
  Serial.println(wifly.getFreeMemory(),DEC);
  Serial1.begin(9600);
  if (!wifly.begin(&Serial1, &Serial)) {
    Serial.println(F("Failed to start wifly"));
    wifly.terminal();
  }

  wifly.setBroadcastInterval(0);	// Turn off UPD broadcast


  //wifly.terminal();
  if(digitalRead(resetButton) == LOW){
    Serial.println("RESET");
    isServer = true;
  } else{
    //EEPROM.write(0, 1);
    isServer = EEPROM.read(0);
    //isServer = true;
  }
  Serial.print(F("MAC: "));
  //wifly.flush();
  //wifly.flushRx();
  //MAC = wifly.getMAC(buf, sizeof(buf));
  Serial.println(wifly.getMAC(MAC, sizeof(MAC)));
  //Serial.print(F("IP: "));
  //Serial.println(wifly.getIP(buf, sizeof(buf)));

  wifly.setDeviceID("Visualight");

  if (wifly.isConnected()) {
    Serial.println(F("Old connection active. Closing"));
    wifly.close();
  }


  wifly.setProtocol(WIFLY_PROTOCOL_TCP);
  if (wifly.getPort() != 80) {
    wifly.setPort(80);
    /* local port does not take effect until the WiFly has rebooted (2.32) */
    wifly.save();
    Serial.println(F("Set port to 80, rebooting to make it work"));
    //wifly.reboot();
    //delay(3000);
  }
  Serial.println(F("Ready"));
  

  if(isServer){
    /* Create AP*/
    Serial.println(F("Creating AP"));
    wifly.createAP("Visualight", "10 i");
    EEPROM.write(0, 1);
    colorLED(255,0,0);
    //    while(wifly.getNumNetworks()== 0){
    //      delay(1500);
    //    }
    //Serial.print(F("Networks: "));
    //Serial.println(wifly.getNumNetworks());

    //scanList = wifly.getScanNew(buf,sizeof(buf));
    //Serial.println(wifly.getScanNew(scanList,sizeof(scanList)));
  }
  else{
    Serial.println(F("Already Configured"));
    while (!wifly.isAssociated()) {
      Serial.println(F("Joining"));
      wifly.join();
      delay(1000);
    }
    isServer = false;
    connectToServer();
    //Already Joined
  }
}
uint32_t connectTime = 0;
void loop()
{
  processButton(resetButton, 5000);
  //button.process();
  if(isServer){
    processServer();
  }
  else{
    processClient();
  }
}

void processClient(){
  //Serial.println("Process Client");
  //delay(100);
  int available;

  if (wifly.isConnected() == false) {
    Serial.println("Not Connected in loop");
    connectToServer();
  } 
  else {
    available = wifly.available();
    if (available < 0) {
      Serial.println(F("Disconnected"));
      wifly.close();
    } 
    else if (available > 1) {
      //Print incoming data...
      if(wifly.read() == 120){
        //Serial.print(wifly.read());
        connectTime = millis();
        _red = wifly.parseInt();
        _green = wifly.parseInt();
        _blue = wifly.parseInt();
        _blinkMe = wifly.parseInt();
        colorLED(_red,_green,_blue);
        //wifly.write('x');
        //Serial.println("data");
      }
      //      Serial.print(_red);
      //      Serial.print(",");
      //      Serial.print(_green);
      //      Serial.print(",");
      //      Serial.print(_blue);
      //      Serial.print(",");
      //      Serial.println(_blinkMe);
      //Serial.write(wifly.read());
    } 
    else {
      //DO Other Stuff HERE
      //Serial.println("Here");
      //delay(50);
      //      if ((millis() - connectTime) > 30000) {
      //        Serial.println("Disconnecting");
      //        wifly.close();
      //      }
      if (wifly.isConnected() == false) {
        Serial.println("Not Connected in loop");
        connectToServer();
      } 
    }

    /* Send data from the serial monitor to the TCP server */
    //    if (Serial.available()) {
    //      wifly.write(Serial.read());
    //    }
  }
}

void processServer(){
  if (wifly.available() > 0) {

    /* See if there is a request */
    if (wifly.gets(buf, sizeof(buf))) {
      //if (strncmp_P(buf, PSTR("GET / "), 6) == 0) {
      if (strstr_P(buf, PSTR("GET /mac")) > 0) {
        /* GET request */
        Serial.println(F("Got GET request"));
        while (wifly.gets(buf, sizeof(buf)) > 0) {
          /* Skip rest of request */
        }
        //int numNetworks = wifly.getNumNetworks();

        sendMac();
        wifly.flushRx();		// discard rest of input
        Serial.println(F("Sent Mac address"));
        //wifly.flush();
        wifly.close();
      } 
      else if (strstr_P(buf, PSTR("GET / ")) > 0) {
        /* GET request */
        Serial.println(F("Got GET request"));
        while (wifly.gets(buf, sizeof(buf)) > 0) {
          /* Skip rest of request */
        }
        //int numNetworks = wifly.getNumNetworks();

        sendIndex();
        wifly.flushRx();		// discard rest of input
        Serial.println(F("Sent index page"));
        //wifly.flush();
        wifly.close();
      } 
      //else if (strncmp_P(buf, PSTR("POST"), 4) == 0) {
      else if (strstr_P(buf, PSTR("POST")) > 0) {
        /* Form POST */

        Serial.println(F("Got POST"));

        /* Get posted field value */
        if (wifly.match(F("network="))) {
          wifly.getsTerm(network, sizeof(network),'&');
          replaceAll(network,"+","$");
          if (wifly.match(F("password="))) {
            wifly.gets(password, sizeof(password));
            replaceAll(password,"+","$");
          }
          wifly.flushRx();		// discard rest of input
          sendGreeting(network);
          Serial.print(F("Sent greeting page - Network: "));
          Serial.print(network);
          Serial.print(F(" Password: "));
          Serial.println(password);
          wifly.flushRx();
          //wifly.flush();
          //wifly.close(); 
          joinWifi();

        }
      } 
      else {
        /* Unexpected request */
        Serial.print(F("Unexpected: "));
        Serial.println(buf);
        delay(100);
        wifly.flushRx();		// discard rest of input
        Serial.println(F("Sending 404"));
        send404();
      }
    }
  }
}

void joinWifi(){
  /* Setup the WiFly to connect to a wifi network */
  wifly.leave();
  //if (!wifly.isAssociated()) {

  //wifly.startCommand();
  //wifly.setSpaceReplace('+');
  wifly.enableDHCP();
  //wifly.setDHCP(WIFLY_DHCP_MODE_ON);
  wifly.setJoin(WIFLY_WLAN_JOIN_AUTO);
  wifly.setChannel("0");
  wifly.setSSID(network);
  wifly.setPassphrase(password);
  //wifly.join();


  //wifly.setIpProtocol(WIFLY_PROTOCOL_TCP);
  wifly.save();
  //wifly.finishCommand();
  wifly.reboot();
  delay(3000);

  //}

  if(!wifly.isAssociated()){
    Serial.println(F("Joining network"));
    if (wifly.join()) {
      Serial.println(F("Joined wifi network"));
      connectToServer();
    } 
    else {
      Serial.println(F("Failed to join wifi network"));
      delay(1000);
      joinWifi();
      //TODO: Reboot count and reset to AP after count expires
    }
  }
  else{
    Serial.println(F("Already Joined!"));
    connectToServer();
  }
}

void connectToServer(){
  wifly.flushRx();
  //MAC = wifly.getMAC(buf, sizeof(buf));
  if (wifly.isConnected()) {
    Serial.println("Old connection active. Closing");
    wifly.close();
  }
  Serial.println("Connecting");
  if (wifly.open("dev.visualight.org",5001)) {
    colorLED(255,255,255);
    Serial.println("Connected: ");
    Serial.print(F("Free memory: "));
    Serial.println(wifly.getFreeMemory(),DEC);
    Serial.flush();
    Serial1.flush();
    Serial.println(MAC);
    //wifly.flush();
    wifly.write(MAC);
    connectTime = millis();
  } 
  else {
    Serial.println("Failed to open");
    delay(1000);
    connectToServer();
  }
  if(isServer){
    Serial.println(F("Client Mode"));
    EEPROM.write(0, 0); 
    isServer = false;
    colorLED(0,0,255);
  }

}

void colorLED(int red,int green,int blue){
  if(sink){
    red = 255-red;
    green = 255-green;
    blue = 255-blue;
  }
  analogWrite(redLED, red);
  analogWrite(greenLED, green);
  analogWrite(blueLED, blue);
}
void fadeOn(){
    for(int fadeValue = 0 ; fadeValue <= 255; fadeValue +=5) { 
    // sets the value (range from 0 to 255):
    colorLED(fadeValue,fadeValue,fadeValue);         
    // wait for 30 milliseconds to see the dimming effect    
    delay(10);                            
  }
}

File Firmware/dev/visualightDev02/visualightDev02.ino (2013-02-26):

/*
 * Bitponics Controller
 * 
 * Ted Hayes / Limina.Studio 2012
 * ted.hayes@liminastudio.com
 * 
 * [License]
 * 
 */

#include <SPI.h>
#include <WiFly.h>
#include <EEPROM.h>
#include <Button.h>

//#define PIN_LED_STATUS          10
#define PIN_BUTTON_RESET        8    // Used to 'factory reset' the system
#define RESET_BUTTON_TIME       8000  // ms, time to hold down button

#define ADHOC_SSID "Visualight"
#define maxLength 50
/////// Globals ////////
String inString = String(maxLength);
char network[20];
char password[20];
int controlNum = 0;
char controlBuff[4];

int _red = 255;
int _green = 255;
int _blue = 255;
int _blinkMe = 0;

long previousMillis = 0;        // will store last time LED was updated
long interval = 100;           // interval at which to blink (milliseconds)
int ledState = HIGH;

const char* MAC;



WiFlyServer server(80);
WiFlyClient bulbClient;
Button resetButton = Button(PIN_BUTTON_RESET,BUTTON_PULLUP_INTERNAL,true,2000);
String scanlist;
boolean wifiSet;

void setup() {
  // Serial ports
  analogWrite(6, _green);
  analogWrite(3, _red);
  analogWrite(5, _blue);
  Serial.begin(9600);
  //  while (!Serial) {
  //    ; // wait for serial port to connect. Needed for Leonardo only
  //  }
  Serial.println("SETUP");
  Serial1.begin(9600);
  WiFly.setUart(&Serial1);
  MAC = WiFly.getMac();
  //EEPROM.write(0, 0);


  // Serial.print("IP: ");
  // Serial.println(WiFly.ip());

  //server.begin();

  // set up factory reset button
  resetButton.holdHandler(factoryReset, RESET_BUTTON_TIME);
  //  if(resetButton.isPressed()){
  //    factoryReset(resetButton);
  //  }

  // Is the unit in Setup or Normal mode?
  wifiSet = EEPROM.read(0);
  //wifiSet = 0;
  if(wifiSet == 1 || wifiSet == true){
    // The WiFi module is set up for wifi, so try to connect to the Bitponics server
    Serial.println("WiFi Mode");
    wifiSet = 1;
    WiFly.begin();
    delay(1000);
    if (bulbClient.connect("leifp.com", 5001)) {
      bulbClient.print(MAC);

      //TODO: 
    } 
    else {
    }
    //This is where we connect to the server
  } 
  else {
    // The WiFi module is NOT set up for wifi and should already be in Adhoc mode, so start web server
    Serial.println("Adhoc Mode");
    setAdhocMode();
  }

  // Misc
  //pinMode(PIN_LED_STATUS, OUTPUT);
}

void factoryReset(Button& b){
  // Serial.print("Held for at least 1 second: ");
  // Serial.println(b.pin);
  Serial.print("factoryReset... ");
  bulbClient.stop();
  boolean adhocOK = setAdhocMode();
  //Serial.println(adhocOK);
  //restart();
}

void restart(){
  // wifi.reboot();
  delay(1000); // wait for reboot to continue
  // setup();    // will this do?

}

boolean setAdhocMode(){
  // sets up the wifi module for Adhoc mode
  // only called by the "Factory Reset" function or first run
  analogWrite(5, 0);
  analogWrite(3, 255);
  analogWrite(6, 0);
  Serial.println("ADHOC Mode");
  boolean sendOK = false;
  WiFly.begin(true);
  if(!WiFly.createAdHocNetwork(ADHOC_SSID)) {
    // set EEPROM value & reboot trigger
    //ERROR
  } 
  else {
    //    Serial.println(F("*** setAdhocMode error"));
    if(EEPROM.read(0)!=0){
      EEPROM.write(0, 0); // means that the device is NOT configured for WiFi, so upon start, perform the correct actions
    }
    wifiSet = 0; // because loop will continue running
    sendOK = true;
  }
  return sendOK;
}


//void returnScanlist(WiFlyClient client){
//  //client.println(scanlist);
//  Serial.println("scanlist");
//}

boolean configWifi(){
  WiFly.begin();
  boolean sendOK = false;
  if (!WiFly.join(network, password)) {
    Serial.print("Association failed. SSID: ");
    Serial.print(network);
    Serial.print(" Password ");
    Serial.println(password);
    delay(5000);
    if (!WiFly.join(network, password)) {
      Serial.println("Association failed.");
      delay(5000);
      if (!WiFly.join(network, password)) {
        Serial.println("Association failed.");
        //delay(1000);
        setAdhocMode();
        //1000
        //0110
        //0
        //0
        //0
        //0
        //0011
      }
    }

  }
  else{
    Serial.println("JOINED");
    analogWrite(5, 0);
    analogWrite(3, 0);
    analogWrite(6, 255);
    EEPROM.write(0, 1);
    wifiSet = 1;
    sendOK = true;
    Serial.println("Connect");
    if (bulbClient.connect("leifp.com", 5001)) {
      bulbClient.print(MAC);

      //TODO: 
    } 
    else {
    }
  }
  return sendOK;

}

void visualight(){
  if (bulbClient.available()>1) {
//    Serial.println("Data");
//    delay(2);
    _red = bulbClient.parseInt();
    _green = bulbClient.parseInt();
    _blue = bulbClient.parseInt();
    _blinkMe = bulbClient.parseInt();
    analogWrite(5, _green);
    analogWrite(3, _red);
    analogWrite(6, _blue);
  }
  if(_blinkMe == 1){
    blinkLED();
  }
  //if we got disconnected reconnect
  if (!bulbClient.connected()) {
    Serial.println("connecting");
    bulbClient.stop();
    //delay(100);
    bulbClient.connect("leifp.com", 5001);
    bulbClient.print(MAC);
    delay(3000);
  } 
}

void blinkLED(){
  unsigned long currentMillis = millis();
  if(currentMillis - previousMillis > interval) {
    previousMillis = currentMillis;
    if (ledState == LOW){
      analogWrite(11, _green);
      analogWrite(10, _red);
      analogWrite(9, _blue);
      ledState = HIGH;
    }
    else{
      analogWrite(11, 0);
      analogWrite(10, 0);
      analogWrite(9, 0);
      ledState = LOW;
    }

  }
}
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

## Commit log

2012-11-21 added dev firmware and PCB design
2012-12-11 Added v3 hardware and v2 firmware
    [LED.brd, LED.sch, VisualightMicroBulb_01.brd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]
2012-12-19 Updates to firmware with MAC address and hardware with ground planes
    [VisualightMicroBulb_02.brd, VisualightMicroBulb_02.sch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]
2013-02-26 lots of changes
    [10w_CREE_LED_driver.brd, 10w_CREE_LED_driver.sch, 10w_LED_driver.brd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]
2013-02-26 changed socket log level
2013-06-21 SO MANY CHANGESgit commit -a -m
    [10w_CREE_LED_driver.brd, 10w_CREE_LED_driver.sch, 10w_CREE_LED_driver_auto.brd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]
2013-08-05 added firmware version 08 and included updates to server
    [LEDdriverSFE_CREE_02.brd, LEDdriverSFE_CREE_02.sch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]
2013-08-16 updates to api docs and file
    [LEDdriverSFE_CREE_02.brd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]
2013-09-26 updaed LED strip files and server
2013-09-26 connected net and socketio outputs
2013-09-26 update to fixe multible bulb switching
2013-10-16 Added prod diy module
    [VisualightMicroDIY_038_gnd.brd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]
2013-10-16 moved prod diy
    [VisualightMicroDIY_038_gnd.brd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]
2013-10-22 working on commenting and connect bug
    [processConnections.ino, visualightDev06.ino, visualightDev06_NoDebug.ino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]
2013-10-22 v038 phoenix and advanced versions
    [VisualightMicroDIY_038_Advanced.brd, VisualightMicroDIY_038_Advanced.sch, VisualightMicroDIY_038_GoldPhoenix.brd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]
2013-10-22 BulbBaseBoard v038 - phoenix and advanced
    [VisualightMicroDIY_038_Advanced.brd, VisualightMicroDIY_038_GoldPhoenix.brd]
2013-10-23 LED board 0024 - phoenix ready
    [SMD_cree_driver_led-mosfet0024-GoldPhoenix.brd, SMD_cree_driver_led-mosfet0024-GoldPhoenix.sch]
2013-10-24 mods for server
    [10w_CREE_LED_driver.brd, 10w_CREE_LED_driver.sch, 10w_CREE_LED_driver_auto.brd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]
2013-10-24 adding latest board files
2013-10-24 added new board files
    [SMD_cree_driver_led-mosfet0024-GoldPhoenix.GBL, SMD_cree_driver_led-mosfet0024-GoldPhoenix.GBO, SMD_cree_driver_led-mosfet0024-GoldPhoenix.GBS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]
2013-10-25 clearing up socket.io logs
2013-10-25 updating socket object reporting
2013-10-25 Updating bulbs as associative array, removing alert, beginning deprication of current-bulb socket.io channel
2013-10-25 updating Bulbs structure and cleaning up handle-sockets file
2013-10-25 cleaning up handle-sockets
2013-10-25 added board files
    [SMD_cree_driver_led-mosfet002_dem.brd, SMD_cree_driver_led-mosfet002_dem.sch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]
2013-10-28 fixing error on close for sockets
2013-10-31 fixing up handle-sockets
2013-11-05 added strip board bom
2013-11-05 fixed merge issue on handle sockets module
2013-11-05 fixing handle-sockets
2013-11-06 inserting group
2013-11-06 robust logging for groups insert
2013-11-06 groups insert fix
2013-11-06 ajax for current groups
2013-11-12 Adding lastest UI changes: subnav, background color, dropdowns, two part buttons
2013-11-13 fixed security titype radio buttons and did some minor css tweeks
2013-11-22 switched button back to polling fixes #17 fixes #7, added cancel to alert when 0 duration is passed fixes #18, added saveStartColor when blinkType is passed as 3 fixes #16
    [Visualight.cpp]
2013-11-22 green and red wifly LEDs disabled in non-debug, updated example sketches with comments
2013-11-22 fixed green LED off, added blinktypes for wifiReset and saveStartColor
    [Visualight.cpp]
2013-11-26 send delete bulb alert when delete button is pressed - removed 3 as option from type slider
2013-11-26 reorganized Hardware folder -- all releases are under eagle folder, added schematic PDFs
    [10w_CREE_LED_driver.brd, 10w_CREE_LED_driver.sch, 10w_CREE_LED_driver_auto.brd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]
2013-11-26 updated eagle files for release folder, renamed folders
    [DIY_037.brd, DIY_037.sch, product_038.brd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]
2013-11-30 updated CSS for navbar button on mobile
2013-12-08 fixed silk error on LED board
    [SMD_cree_driver_led-mosfet0024-GoldPhoenix.brd, SMD_cree_driver_led-mosfet0024-GoldPhoenix.sch]
2013-12-09 redesigned landing page
2013-12-16 added wifly LED flag to setup(), method for enabling/disabling, updated example

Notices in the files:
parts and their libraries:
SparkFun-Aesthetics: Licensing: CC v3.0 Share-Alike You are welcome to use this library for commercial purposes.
